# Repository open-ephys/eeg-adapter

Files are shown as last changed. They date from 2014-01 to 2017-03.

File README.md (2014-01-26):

eeg-adapter
===========

Adapters for using open-ephys for human EEG

Also see the wiki category at https://open-ephys.atlassian.net/wiki/display/OEW/EEG for more info.

Specifications
-----------

EEG breakout board currently supports two connector types: P50 and 40 PIN

- P50 connector Manufactured by EASYCAP (Germany) 
   - **Compatible Systems:** BrainVision (BrainProducts, GmbH) 
   - **Channels:** 32+ channels
   - **Caps:** actiCAP, BrainCap Fast'nEasy, EasyCap, EasyCap active, Fast'nEasy Cap.
   - **Pitch:** 0.05"
   - **Ground:** Third column from the left, first pad at the bottom.
   - **Reference:** First column on the left, 7 pads up from the bottom.

- 40 PIN connector Manufactured by Compumedics Neuroscan (United States)
   - **Compatible Systems:** MagLink, CURRY Scan 7 (Neuroscan, USA)
   - **Channels:** 40+ Channels.
   - **Caps:** Quik-Cap.
   - **Pitch:** 0.1"
   - **Ground:** Bottom row 16 headers in from the left.
   - **Reference:** Top row 7 headers in from the left.

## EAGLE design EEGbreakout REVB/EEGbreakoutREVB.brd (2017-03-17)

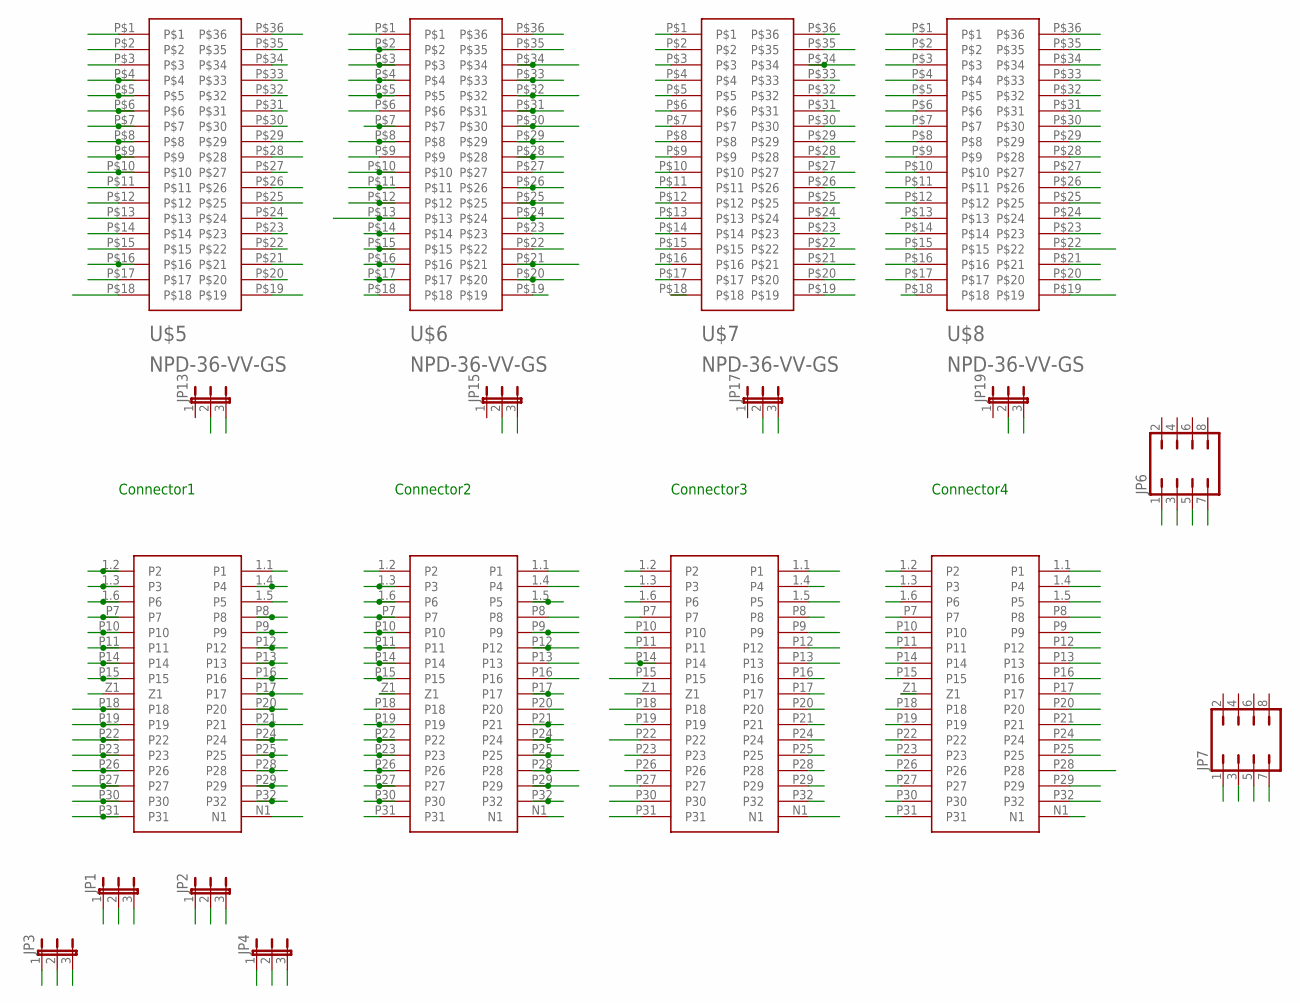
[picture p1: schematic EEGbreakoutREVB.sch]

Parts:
JP1, JP2, JP3, JP4, JP13, JP15, JP17, JP19: JP2E; JP2
JP6, JP7: JP4Q
U$1, U$2, U$3, U$4: P50; CON-MOLEX_71061-0003SM
U$5, U$6, U$7, U$8: NPD-36-VV-GS

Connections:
1.1: U$1.1.1 (P1), U$5.P$2
1.2: U$1.1.4 (P4), U$5.P$3
1.3: U$1.1.5 (P5), U$5.P$4
1.4: U$1.P8, U$5.P$5
1.5: U$1.P9, U$5.P$6
1.6: U$1.P12, U$5.P$7
1.7: U$1.P13, U$5.P$8
1.8: U$1.P16, U$5.P$9
1.9: U$1.P17, U$5.P$10
1.10: U$1.P20, U$5.P$11
1.11: U$1.P21, U$5.P$12
1.12: U$1.P24, U$5.P$13
1.13: U$1.P25, U$5.P$14
1.14: U$1.P28, U$5.P$15
1.15: U$1.P29, U$5.P$16
1.16: U$1.P32, U$5.P$17
1.17: U$1.1.2 (P2), U$5.P$20
1.18: U$1.1.3 (P3), U$5.P$21
1.20: U$1.P7, U$5.P$23
1.21: U$1.P10, U$5.P$24
1.22: U$1.P11, U$5.P$25
1.23: U$1.P14, U$5.P$26
1.24: U$1.P15, U$5.P$27
1.25: U$1.P18, U$5.P$28
1.26: U$1.P19, U$5.P$29
1.27: U$1.P22, U$5.P$30
1.28: U$1.P23, U$5.P$31
1.29: JP4.2, U$5.P$32
1.30: JP2.2, U$5.P$33
1.31: JP1.2, U$5.P$34
1.32: JP3.2, U$5.P$35
2.1: U$2.1.1 (P1), U$6.P$2
2.2: U$2.1.4 (P4), U$6.P$3
2.3: U$2.1.5 (P5), U$6.P$4
2.4: U$2.P8, U$6.P$5
2.5: U$2.P9, U$6.P$6
2.6: U$2.P12, U$6.P$7
2.7: U$2.P13, U$6.P$8
2.8: U$2.P16, U$6.P$9
2.9: U$2.P17, U$6.P$10
2.10: U$2.P20, U$6.P$11
2.11: U$2.P21, U$6.P$12
2.12: U$2.P24, U$6.P$13
2.13: U$2.P25, U$6.P$14
2.14: U$2.P28, U$6.P$15
2.15: U$2.P29, U$6.P$16
2.16: U$2.P32, U$6.P$17
2.17: U$2.1.2 (P2), U$6.P$20
2.18: U$2.1.3 (P3), U$6.P$21
2.19: U$2.1.6 (P6), U$6.P$22
2.20: U$2.P7, U$6.P$23
2.21: U$2.P10, U$6.P$24
2.22: U$2.P11, U$6.P$25
2.23: U$2.P14, U$6.P$26
2.24: U$2.P15, U$6.P$27
2.25: U$2.P18, U$6.P$28
2.26: U$2.P19, U$6.P$29
2.27: U$2.P22, U$6.P$30
2.28: U$2.P23, U$6.P$31
2.29: U$2.P26, U$6.P$32
2.30: U$2.P27, U$6.P$33
2.31: U$2.P30, U$6.P$34
2.32: U$2.P31, U$6.P$35
3.1: U$3.1.1 (P1), U$7.P$2
3.2: U$3.1.4 (P4), U$7.P$3
3.3: U$3.1.5 (P5), U$7.P$4
3.4: U$3.P8, U$7.P$5
3.5: U$3.P9, U$7.P$6
3.6: U$3.P12, U$7.P$7
3.7: U$3.P13, U$7.P$8
3.8: U$3.P16, U$7.P$9
3.9: U$3.P17, U$7.P$10
3.10: U$3.P20, U$7.P$11
3.11: U$3.P21, U$7.P$12
3.12: U$3.P24, U$7.P$13
3.13: U$3.P25, U$7.P$14
3.14: U$3.P28, U$7.P$15
3.15: U$3.P29, U$7.P$16
3.16: U$3.P32, U$7.P$17
3.17: U$3.1.2 (P2), U$7.P$20
3.18: U$3.1.3 (P3), U$7.P$21
3.19: U$3.1.6 (P6), U$7.P$22
3.20: U$3.P7, U$7.P$23
3.21: U$3.P10, U$7.P$24
3.22: U$3.P11, U$7.P$25
3.23: U$3.P14, U$7.P$26
3.24: U$3.P15, U$7.P$27
3.25: U$3.P18, U$7.P$28
3.26: U$3.P19, U$7.P$29
3.27: U$3.P22, U$7.P$30
3.28: U$3.P23, U$7.P$31
3.29: U$3.P26, U$7.P$32
3.30: U$3.P27, U$7.P$33
3.31: U$3.P30, U$7.P$34
3.32: U$3.P31, U$7.P$35
4.1: U$4.1.1 (P1), U$8.P$2
4.2: U$4.1.4 (P4), U$8.P$3
4.3: U$4.1.5 (P5), U$8.P$4
4.4: U$4.P8, U$8.P$5
4.5: U$4.P9, U$8.P$6
4.6: U$4.P12, U$8.P$7
4.7: U$4.P13, U$8.P$8
4.8: U$4.P16, U$8.P$9
4.9: U$4.P17, U$8.P$10
4.10: U$4.P20, U$8.P$11
4.11: U$4.P21, U$8.P$12
4.12: U$4.P24, U$8.P$13
4.13: U$4.P25, U$8.P$14
4.14: U$4.P28, U$8.P$15
4.15: U$4.P29, U$8.P$16
4.16: U$4.P32, U$8.P$17
4.17: U$4.1.2 (P2), U$8.P$20
4.18: U$4.1.3 (P3), U$8.P$21
4.19: U$4.1.6 (P6), U$8.P$22
4.20: U$4.P7, U$8.P$23
4.21: U$4.P10, U$8.P$24
4.22: U$4.P11, U$8.P$25
4.23: U$4.P14, U$8.P$26
4.24: U$4.P15, U$8.P$27
4.25: U$4.P18, U$8.P$28
4.26: U$4.P19, U$8.P$29
4.27: U$4.P22, U$8.P$30
4.28: U$4.P23, U$8.P$31
4.29: U$4.P26, U$8.P$32
4.30: U$4.P27, U$8.P$33
4.31: U$4.P30, U$8.P$34
4.32: U$4.P31, U$8.P$35
C1.29: JP4.1, U$1.P26
C1.30: JP2.1, U$1.P27
C1.31: JP1.1, U$1.P30
C1.32: JP3.1, U$1.P31
GND: JP13.3, JP15.3, JP17.3, JP19.3, U$1.N1, U$2.N1, U$3.N1, U$4.N1, U$5.P$1, U$5.P$19, U$6.P$1, U$6.P$19, U$7.P$1, U$7.P$19, U$8.P$1, U$8.P$19
J29: JP4.3, JP6.1
J30: JP2.3, JP6.3
J31: JP1.3, JP6.5
J32: JP3.3, JP6.7
unnamed: U$1.1.6 (P6), U$5.P$22
REF: JP7.1, JP13.2, U$1.Z1, U$5.P$18, U$5.P$36
REF1: JP7.3, JP15.2, U$2.Z1, U$6.P$18, U$6.P$36
REF2: JP7.5, JP17.2, U$3.Z1, U$7.P$18, U$7.P$36
REF3: JP7.7, JP19.2, U$4.Z1, U$8.P$18, U$8.P$36

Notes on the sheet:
Connector1
Connector2
Connector3
Connector4

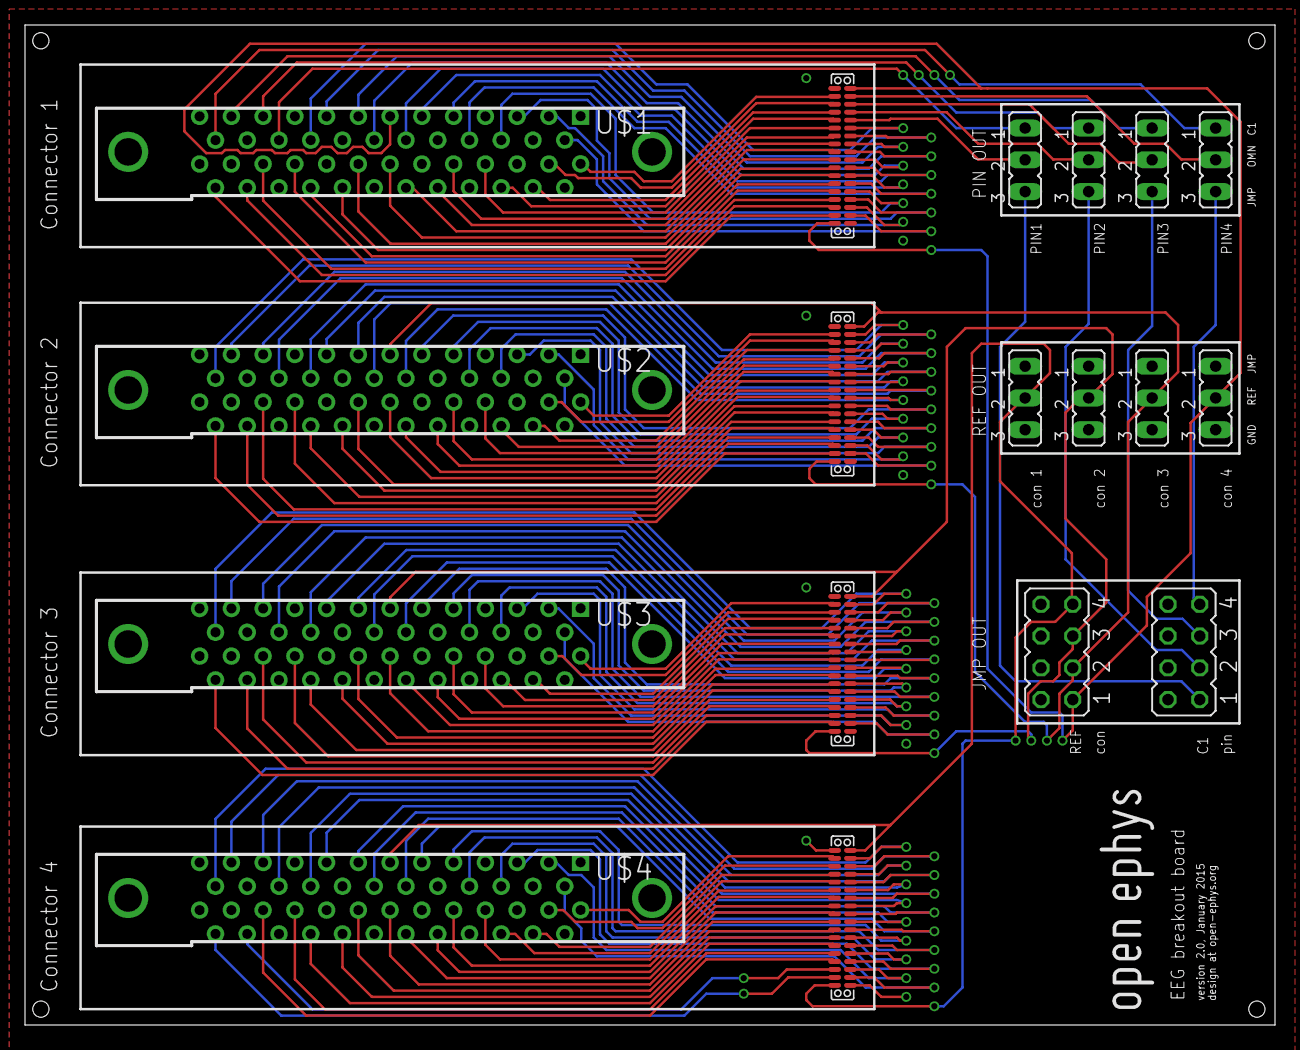
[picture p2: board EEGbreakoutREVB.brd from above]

Board: 2 copper layers, 100.0 x 80.0 mm, 19 parts (0 on the bottom side), 141 nets.

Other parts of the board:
U$9: OPEN_EPHYS_LOGO

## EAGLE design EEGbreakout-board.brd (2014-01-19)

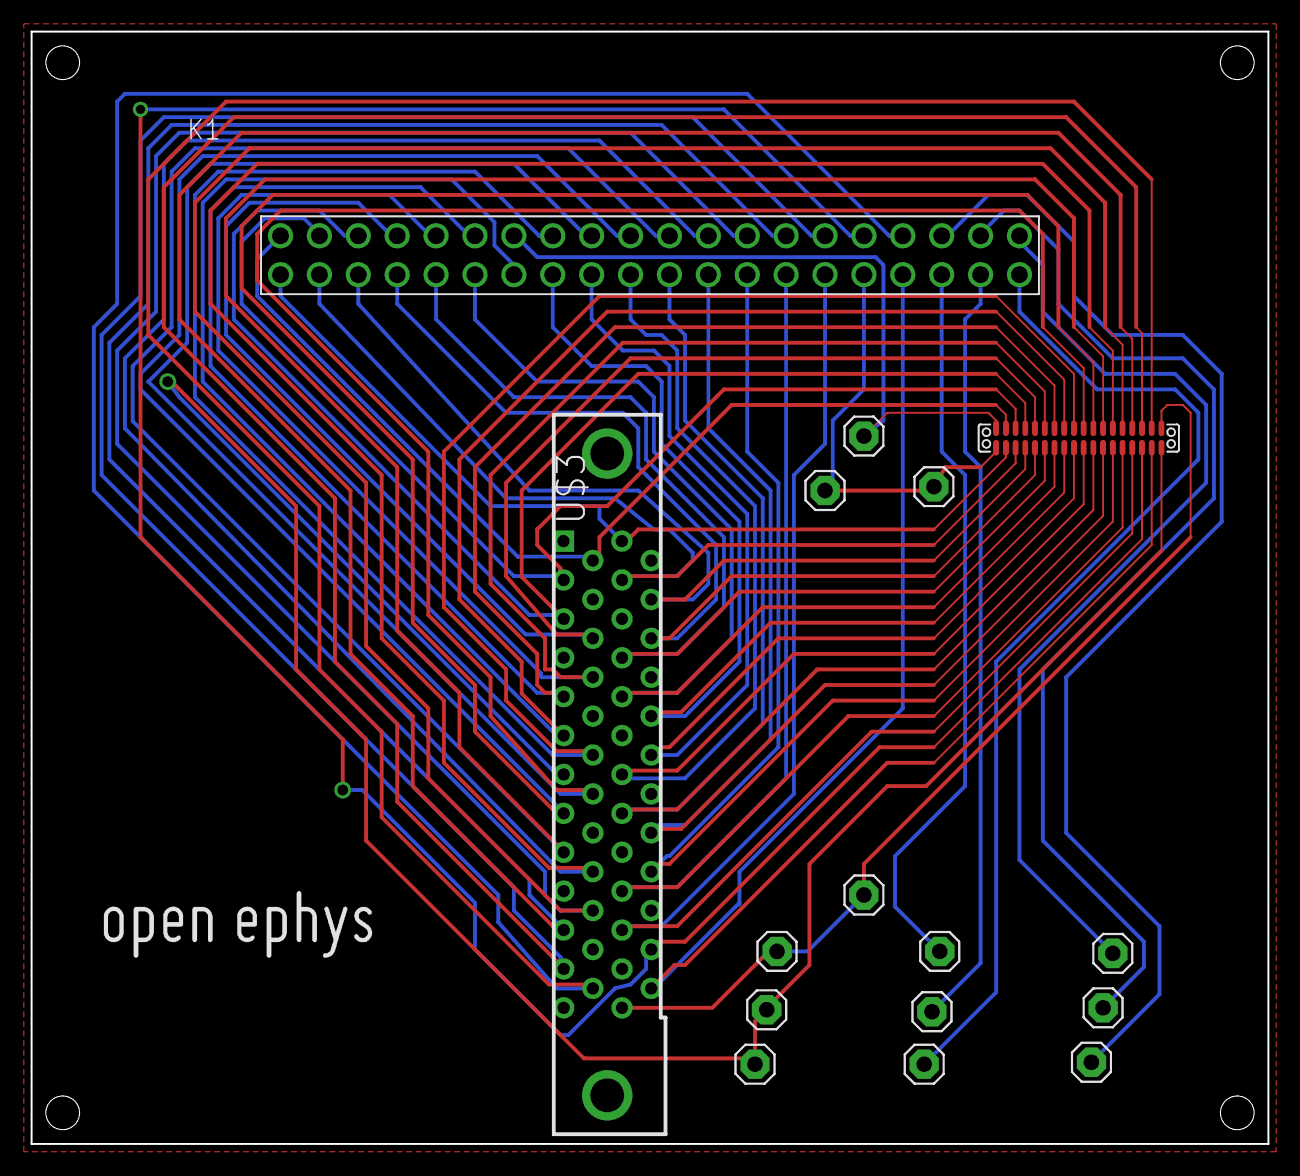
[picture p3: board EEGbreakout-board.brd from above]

Board: 2 copper layers, 80.8 x 72.6 mm, 17 parts (0 on the bottom side), 40 nets.

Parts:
GND: 1X01
JP1, JP2, JP3, JP4, JP5, JP6, JP7, JP8, JP9, JP10, JP11, JP12: 1X01
K1: 61304021121
U$1: OPEN_EPHYS_LOGO
U$2: NPD-36-VV-GS
U$3: EZCF; CON-MOLEX_71061-0003SM

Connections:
GND: GND.1, JP7.1, JP8.1, JP9.1, K1.25, U$2.P$1, U$2.P$19, U$3.N1
unnamed: JP6.1, K1.1
unnamed: JP5.1, K1.2
unnamed: JP4.1, K1.3
unnamed: JP3.1, K1.23
unnamed: JP2.1, K1.22
unnamed: JP1.1, K1.21
unnamed: K1.20, U$2.P$35, U$3.P2
unnamed: K1.19, U$2.P$34, U$3.P3
unnamed: K1.18, U$2.P$33, U$3.P6
unnamed: K1.17, U$2.P$32, U$3.P7
unnamed: K1.16, U$2.P$31, U$3.P10
unnamed: K1.15, U$2.P$30, U$3.P11
unnamed: K1.34, U$2.P$29, U$3.P14
unnamed: K1.13, U$2.P$28, U$3.P15
unnamed: K1.12, U$2.P$27, U$3.P18
unnamed: K1.11, U$2.P$26, U$3.P19
unnamed: K1.10, U$2.P$25, U$3.P22
unnamed: K1.9, U$2.P$24, U$3.P23
unnamed: K1.8, U$2.P$23, U$3.P26
unnamed: K1.7, U$2.P$22, U$3.P27
unnamed: K1.6, U$2.P$21, U$3.P30
unnamed: K1.4, U$2.P$20, U$3.P31
unnamed: K1.24, U$2.P$17, U$3.P32
unnamed: K1.5, U$2.P$16, U$3.P29
unnamed: K1.26, U$2.P$15, U$3.P28
unnamed: K1.27, U$2.P$14, U$3.P25
unnamed: K1.28, U$2.P$13, U$3.P24
unnamed: K1.29, U$2.P$12, U$3.P21
unnamed: K1.30, U$2.P$11, U$3.P20
unnamed: K1.31, U$2.P$10, U$3.P17
unnamed: K1.32, U$2.P$9, U$3.P16
unnamed: K1.33, U$2.P$8, U$3.P13
unnamed: K1.35, U$2.P$7, U$3.P12
unnamed: K1.36, U$2.P$6, U$3.P9
unnamed: K1.37, U$2.P$5, U$3.P8
unnamed: K1.38, U$2.P$4, U$3.P5
unnamed: K1.39, U$2.P$3, U$3.P4
unnamed: K1.40, U$2.P$2, U$3.P1
REF: JP10.1, JP11.1, JP12.1, K1.14, U$2.P$18, U$2.P$36, U$3.Z1

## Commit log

2014-01-19 Create EEGbreakout-board.brd
    adapter layout for P50 and 40 pin connector
    [EEGbreakout-board.brd]
2014-01-19 Remove part description info that Eagle v6.3 had trouble loading
    [EEGbreakout-board.brd]
2014-01-23 EEG breakout Gerber
    Sunstone Gerber files for EEG adapter board
2014-01-23 Create EEGbreakout connector info
    Connector Specs for EEG adapter
2014-03-12 Update for EEG adapter
    Contains Gerber files for PCB production by Seeed Studios
    [EEG_breakoutboard_V01.GBL, EEG_breakoutboard_V01.GBO, EEG_breakoutboard_V01.GBP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]
2017-03-17 EEG breakoutboard REVB
    Second version of EEG breakoutboard. Allows for up to 128 channels of EEG, with up to four interchangeable channels for other ephys measurements.
    [EEGbreakoutREVB.GBL, EEGbreakoutREVB.GBO, EEGbreakoutREVB.GBP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]

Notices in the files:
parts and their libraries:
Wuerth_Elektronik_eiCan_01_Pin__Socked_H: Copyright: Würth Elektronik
